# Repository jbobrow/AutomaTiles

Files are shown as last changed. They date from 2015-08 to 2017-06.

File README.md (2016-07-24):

# AutomaTiles

Read [here](GamePlatform.md) to learn about how to think of AutomaTiles as a game platform

AutomaTiles presents a new way to interact with cellular automata. In a physical form, each tile can be manipulated, and progresses based on an external metronome or user input. The same intimate knowledge a movie editor has with a film is shared with computation, as the user can control the speed at which the system evolves and handle individuals as they respond to input.

## Components
1. Virtual AutomaTiles
    1. [Automatiles.com/sim](http://automatiles.com/sim) (written by Jonathan Bobrow, rendered w/ Two.js)
    2. [Automatiles.com/sim/emoji](http://automatiles.com/sim/emoji) (modified version of Nicky Case's Emoji World Simulator)
2. Tangible AutomaTiles
    1. Hardware
        1. Electronics ([Components](https://docs.google.com/spreadsheets/d/1YpmN0rzX8dJSE3OYGx2io3yXud3R6zgf5WAVNdhyiFE))
        2. Printed Circuit Boards ([Rev. 3](http://automatiles.tumblr.com/post/133176987321/rev-3-boards-batch-of-100-automatiles-so-much-to))
        3. [Case Designs + Models](http://automatiles.tumblr.com/post/143452350711/automatiles-w-silicon-jackets-for-members-week)
    2. Firmware
        1. Registers, Pin mapping...
        2. Low Level code not accessible in API
    3. API
        1. [AutomaTile Library](Arduino)
        2. [Documentation](Examples/API.md)
        3. [Example Code](Examples)

##License
Copyright (c) 2015 MIT

Permission is hereby granted, free of charge, to any person obtaining a copy of this software and associated documentation files (the "Software"), to deal in the Software without restriction, including without limitation the rights to use, copy, modify, merge, publish, distribute, sublicense, and/or sell copies of the Software, and to permit persons to whom the Software is furnished to do so, subject to the following conditions:

The above copyright notice and this permission notice shall be included in all copies or substantial portions of the Software.

THE SOFTWARE IS PROVIDED "AS IS", WITHOUT WARRANTY OF ANY KIND, EXPRESS OR IMPLIED, INCLUDING BUT NOT LIMITED TO THE WARRANTIES OF MERCHANTABILITY, FITNESS FOR A PARTICULAR PURPOSE AND NONINFRINGEMENT. IN NO EVENT SHALL THE AUTHORS OR COPYRIGHT HOLDERS BE LIABLE FOR ANY CLAIM, DAMAGES OR OTHER LIABILITY, WHETHER IN AN ACTION OF CONTRACT, TORT OR OTHERWISE, ARISING FROM, OUT OF OR IN CONNECTION WITH THE SOFTWARE OR THE USE OR OTHER DEALINGS IN THE SOFTWARE.

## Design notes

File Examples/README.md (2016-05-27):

##AutomaTiles Examples##
The following examples are written using the AutomaTiles API for the Arduino IDE.

###Instructions for using the Arduino IDE w/ AutomaTiles###
1. copy the `AutomaTiles` folder into your Arduino directory i.e. `~/Documents/Arduino/hardware/`
2. launch or quit and relaunch Arduino IDE
3. in the top menu, go to `Tools > Board` and select `AutomaTile`
4. open an example and press the checkmark to make sure it compiles
5. Use an ISP of your choice and program your AutomaTiles!

###Examples###
**Color Gossip**
An example to show how colors can transition smoothly between each other. In this aesthetic example, tiles pulse white when alone, and then share colors when together. Pressing on one changes its color, and surrounding tiles try to match the color while transitioning smoothly over 3 seconds. With a large population, the result is a flow of colors, it is up to chance which one will contaminate them all.  

**Game of Life**
Based on John Conway's [Game of Life](https://en.wikipedia.org/wiki/Conway%27s_Game_of_Life), this example follows a simple set of rules to emerge some very complex behavior. Different AutomaTile arrangements create multiple static and dynamic equilibria

**Forest Fire**
A forest fire simulation based on Nicky Case's [Simulating the World in Emoji](ncase.me/simulating). Each tile represents a plot of land that can grow a tree, be struck by lightning, and catch on fire. Fires spread, Trees grow back, can you create the most resilient forest?

**Fracture**
A game that capitalizes on simple rules and thinking with your hands. Fracture is a competitive game for diversity. Each player has a color and they are trying to make all of their (6) tiles happy, represented by blinking. To make a tile happy, it needs to have at least 2 neighbors and only be touching colors different from itself. Players move by "fracturing" the board into 2 parts and reconfiguring it to make themselves more diverse and their opponents less diverse.

**PrototypeColors**
This is your best friend for prototyping any game. Tiles will shine brightly one a a predefined set of colors, in this case: red, orange, yellow, green, cyan, blue, magenta. If pressed the tile will switch to blink that color, or blink faster with another press. Holding down a tile for >1 sec goes to the next color and double pressing the tile <1 sec goes back to the previous color. With these easy deterministic rules that are not affected by neighbors, you can imagine how a game could work before having to program how it does work.

**Rock, Paper, Scissors**
A simple ruleset that results in a trippy chase of colors. Looks quite similar to a BZ-reaction.

**WireWorld**
A simple rulest based on [Wireworld](https://en.wikipedia.org/wiki/Wireworld), a cellular automata design of Brian Silverman in 1987. This ruleset simulates the flow of electrons through conductive wiring. Each electron is represented with a head and a tail for direction or flow of current, and spaces that aren't wires are fittingly considered insulation. The hexagonal ruleset requires a redefinition of logic gates (if all are possible)

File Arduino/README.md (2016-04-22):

# Arduino Board Type
Just add this folder to your <ARDUINO>\hardware\ directory.

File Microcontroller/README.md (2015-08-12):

# Microcontroller code
This is the code and libraries that will be running on the AutomaTiles. It handles all aspects of their operation.

## Programming Instructions
The ISP should be attached with Pin 1 towards the silk screened label and a coin cell should be in the device. The most recent stable build will be in AutomaTilesMain/AutomaTilesMain/Release, although the project can be easily rebuilt by opening it in Atmel Studio. As the clock speed of the ATTiny84 is only 1 MHz, any programming clock should be kept below 1/4 of that or 250kHz. To program from within Atmel Studio, open Tools>Device Programming and set your tool. Make sure to change the data clock to an appropriate value. Read the device signature to ensure you have communication. If that succeeds, go to the memories tab, ensure the proper .elf file is selected for the flash, and hit program.

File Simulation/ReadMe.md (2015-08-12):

# HTML Simulation

## Overview
A simulation of cellular automata in which the grid can be alternated between triangle, square, and hexagon. The neighborhoods update for each cell and the transition is animated, showing that each cell maintains its state. Rulesets should be user set and switchable through a GUI.

## File Structure
index.html
css/
js/

## Dependencies

1. Two.js
2. JQuery.js

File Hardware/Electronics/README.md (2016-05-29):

##AutomaTiles Electronics##
-	Eagle Parts (Library)
-	Schematics
-	Boards
-	Build of Materials (BOM)
-	Datasheets (maybe just links)

... anything else relevant to electronics

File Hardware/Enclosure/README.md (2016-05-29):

##AutomaTiles Enclosure##
-	Fusion360 models (maybe just links)
-	STLs
-	Build of Materials (BOM)

... anything else relevant to the enclosure

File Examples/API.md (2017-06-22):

## AutomaTiles API ##

Since the API is quite short, this is the current documentation for using it. It should be apparent on how to use it from some of the examples, but this can serve as a nice reference while you are writing your first programs for the AutomaTiles. 

**A default blank sketch**
```c
void setup() {  
   setButtonCallback(button); 
   setStepCallback(step);
}

void loop() {
	// continuous time logic here
}

void button() {
	// handle button down here
}

void step() {
	// discrete time logic here
}

```

### AutomaTile methods ###

**getNeighborStates**
```c
void getNeighborStates(uint8_t * result);
// pass it an array for the size of the neighborhood and it will return each neighbor’s state in that array. 
```
**sendStep**
```c
void sendStep(void);
// step forward in time, simulate ruleset
// maximum frequency 10Hz
// these do not cue up, i.e. if you send step more frequently, steps will be dropped 
```
**getTimer**
```c
uint32_t getTimer(void);
// returns a value of time in milliseconds (starts at 0 from battery in) 
```
**setColor**
```c
void setColor(const uint8_t color[3]);
// send this function (R,G,B) 0-255, color will change on next cycle 
```
**setState**
```c
void setState(uint8_t state);
// set the state of self 0-15 (limited due to communication of state and step frequency)
// invalid states are ignored, i.e. return without state change
// NOTE: empty spaces act as tiles of state 0 (treat this accordingly) 
```
**getState**
```c
uint8_t getState(void);
// get’s our own current state, 0-15 
```
**setStepCallback**
```c
void setStepCallback(cb_func cb); 
// pass your own function to setStepCallback, this function takes no arguments and returns nothing
// can be set once in the beginning of your application, but can also be hot-swapped during runtime
// defaults to do nothing (change this to default to flash red… or white) 
```
**setButtonCallback**
```c
void setButtonCallback(cb_func cb);
// pass your own function to setButtonCallback, this function takes no arguments and returns nothing
// can be set once in the beginning of your application, but can also be hot-swapped during runtime
// defaults to do nothing (change this to default to flash blue)
// NOTE: you cannot delay in the button callback (i.e. timer will not update while you are in the callback) 
```
**setLongButtonCallback**
```c
void setLongButtonCallback(cb_func cb, uint16_t ms);
// pass your own function to setLongButtonCallback, this function takes no arguments and returns nothing
// long button callback will be activated after a button has been pressed for n milliseconds (second parameter)
// can be set once in the beginning of your application, but can also be hot-swapped during runtime
// defaults to do nothing (change this to default to flash blue)
// NOTE: you cannot delay in the button callback (i.e. timer will not update while you are in the callback) 
```
**setLongButtonCallbackTime**
```c
void setLongButtonCallbackTime(uint16_t ms);
// set the amount of time it takes before the longButtonCallback is triggered
// can be hot-swapped during runtime
```
**setTimerCallback**
```c
void setTimerCallback(cb_func cb, uint16_t ms);
// set a custom timed callback, whatever you want, it will fire after a given amount of time
// can be hot-swapped during runtime
```
**setTimerCallbackTime**
```c
void setTimerCallbackTime(uint16_t ms);
// set the time for your callback seperately (maybe you want to update that time after setting it initially, perhaps it evolves over time
// can be hot-swapped during runtime
```
**setTimeout**
```c
void setTimeout(uint8_t seconds);
// sets the amount of time before sleeping in seconds
// defaults to 20 seconds
// if you want the automatile to never sleep send it 0, this will run down your battery 
```
**setMicOn**
```c
void setMicOn(void);
// turns the microphone on (i.e. listens for snaps) 
```
**setMicOff**
```c
void setMicOff(void);
// turns the microphone off (i.e. only steps forward from neighbor notification) 
```

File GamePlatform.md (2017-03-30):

# AutomaTiles as Game Platform

AutomaTiles allow a new type of game play as well as game design, and the following document will give a quick overview as to how to design for AutomaTiles and what their unique capabilities are.

## Overview

First of all, what are AutomaTiles? Each AutomaTile is a "smart" hexagonal tile, designed to be held in the hand or placed next to other tiles on a table. Magnets inside of each AutomaTile allow the hexagonal tile to maintain an organized gridlike structure without needing a board. Each tile has 3 properties:
1. it responds to presses (this is a tactile button press, the entire tile depresses ever so slightly, so players can feel when they have pressed on a tile, not simply touched)
2. it is social, which means it is aware of its neighbors, tiles on other sides, both presence as well as state (explained further below)
3. it is rythmic, can respond to sound (currently treated as a global message, for example a time step forward)

## Outputs

AutomaTiles communicate to the players through RGB illumination and their hue, saturation, brightness, as well as animated properties (i.e. pulsing, blinking, flashing...). Their is only a single uniform illumination for the entire tile, so think of each tile as being able to communicate relatively simple information.
In one example, a tile shows it is in a win condition by blinking rapidly, so all players are aware of the game state.

While illumination is how a single tile communicates to the players, the arrangement of the tiles also communicates something to the players. In one example, the arrangement of 10 tiles into different forms creates different behaviours of the whole. For example, if the tiles are representing trees in a forest fire, a tightly packed set of 10 will spread the fire quicker than a long single file line of tiles(trees). The player can reason this by seeing the arrangement of the board, and conversely, affect it by rearranging the board. Which brings me to inputs.

## Inputs

The simplest of inputs is a press. Each tile acts as a mechanical momentary button. The button can be used in a variety of ways, and can respond to a quick press, a long press, a double press...

The button press can be an input to change the state of a tile, or inform the tile of a users action. For example, in the forest fire ruleset, a single press strikes lightning upon a tile. If the tile is a tree, it will then change state to be on fire, and if it is not a tree, it will simply go on being not a tree, as well as not on fire.

The press can also be used to reveal information contained in a tile. For example, a tile representing a place in a game of minesweeper could reveal that it has a mine under it only when held with a long press. The button press in this case didn't add information to the system but is simply used to reveal information.

## Tile Communication

The tiles communicate with each of their six tile neighbors by receiving information every ~20 times per second. The information passed is in the form of a single integer (0-16). If no tile is present on a single side, the tile reads 0 on that side. (A tile can be present and send 0 as well, but it will be treated the same as space without a tile). What does this mean in simple terms? This means that each tile can tell each neighboring tile that it is in one of roughly 15 states. In the forest fire example, there are 3 states: tree, fire, soil. But what about lightning? that isn't a state, since it only affects the local tile, so it is animated through the illumination, but simply changes the tile's state from tree to fire.

AutomaTiles are setup to do this kind of communication often and reliably, but it is not the only way they can communicate. For longer forms of information, such as passing string-like information, there is a shared data buffer that could be utilized. This is experimental and not refined in the API, so I recommend first trying to rely on simple communication with the dozen or so states afforded above.

## Time

Game time for the tiles can be continuous, evaluating their state 20 times a second, or they can be discrete, evaluating their state only when a step is called. The step can be heard from the microphone or sensed via a pacemaker(special AutomaTile that silently flashes in the same way a metronome clicks).

In the forest fire example, time is discrete, which makes the spread of the fire controlled by the speed of the metronome. One could see this as a game mechanic, where each turn is a click or step forward.

In the game Fracture, a continuous game, the tiles are constantly evaluating their state so they can show players the most up to date representation of the current board state. This results in a board that is quickly responsive to arrangement, while discrete time makes a board that feels responsive to sound, pacemaker, or simply discrete time.

## Random vs. Deterministic

AutomaTiles can respond to their inputs and neighbors deterministically, where they will respond exactly the same way given the same inputs and neighbors everytime. This is the case in the example of Fracture or Game of Life. Players can learn how tiles will behave given a certain arrangement because of this deterministic ruleset.

Games often use randomness for a bit of chance involved in each move. A dice roll, or a weighted random value can be very useful in creating suspense or capturing the real world uncertainty.

Randomness can also be used with AutomaTiles with a bit of care and caution. Randomness is currently based on the internal clock of the ATtiny, which can provide a good enough source for a dice roll. In the example of the forest fire, each tile (plot of land) has an n% chance of growing a tree. That percent increases with the number of neighboring trees, to represent fertile ground, but it is random none-the-less. The caviat with randomness and AutomaTiles is that players must feel like the tiles are giving signal, not simply noise. If a player can't understand why a tile is behaving in the way it is, it will be confusing for everyone. That said, it is not a technical limitation, if you want a tile to be a random different color every time you press it, that is an easy program to write.

## Memory

While tiles can maintain a bit of a memory or history of what they have done, neighbors they've had, or how much time has passed, this is limited and it is important to remember that if this isn't transparent to the player, it will be very confusing. However, there will be elegant solutions in which a bit of stygmergy might just seep its way into a game and shed light on a beautiful invisible system that lies just beneath the surface.
(more on program space below)

## Trickiness

As you might have noticed, you have complete control over the way a tile displays itself to the player and the state a tile is actually in. It might be useful to have many states an only 2 visibly different appearances to the players. Conversely, it might be useful to have only two states and show many different illuminations.

The possibilities are many, feel free to look through the samples, they are only a few, but cover a couple of use cases.

Please feel free to ask about features, and if I didn't cover something that is in the API, I should, so point it out, it belongs here, too!

## Tech Details (for the game designer)

Each tile has it's own brain(attiny) with which it can run its own set of instructions. The examples I have given so far have the exact same code on every tile and the properties of the tiles together could be referred to as _emergent_. Game design with different code on some tiles vs others is also possible but might requires a skin or mark of some sort to differentiate the tiles (if the colors don't already suggest seperation).

### Memory

The ATtiny84 contains 8k of memory. The AutomaTiles firmware (or core library) takes up just under half of this space (~4k). That leaves an additional 4k for you to program your application.

The forest fire example uses ~5k memory (i.e. that application is only about 1k)

The game Fracture uses ~6k memory (... 2k application)

Additionally, there are 512 bytes of dynamic memory or RAM, which will be used for your global variables as well as your stack. If you use up all of that space with global variables, there will be no room for the stack and so weird sh...stuff will happen. Here is a nice breakdown of [memory management on AVR](http://thegaragelab.com/conserving-memory-on-an-avr/).

The space is limited, which suggests simple rules and straightforward code, which is beneficial to the players as well, since the aggregate always feels more complex than the single tile. When programming the tiles, optimizations for space can be made such as being specific about the types of variables. For example, using a `uint8_t` (1 byte... 8 bits) is a space efficient way to hold numbers 0-255, while using an `int` or an `uint16_t`(2 bytes... 16 bits) might be wasteful.

At first this task of memory management could seem daunting, but in practice, I have found the exercise of being concise and clever with code quite rewarding. Additionally, the Arduino IDE will let you know exactly how much space you are using everytime you press compile. If you open up a blank AutomaTile sketch and press compile, you will see that the sketch is ~4k (49%)
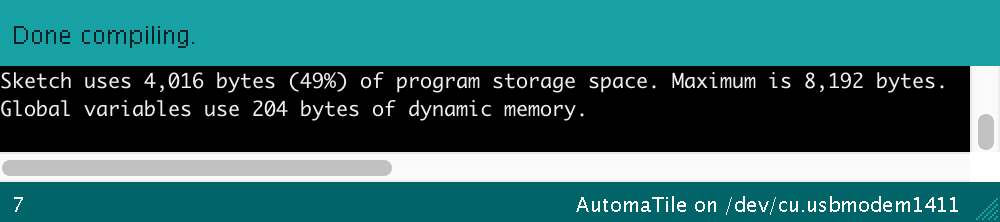
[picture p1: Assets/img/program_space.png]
Arduino IDE Screenshot


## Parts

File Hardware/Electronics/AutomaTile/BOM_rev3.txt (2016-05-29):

QUANTITY	PART NUMBER	Value	Device	Package	CUSTOMER REFERENCE	Description
1	1276-5110-1-ND	100k	R-US_R0603	R0603	R18	"RESISTOR, American symbol"
2	490-1532-1-ND	100nF	C-EUC0603	C0603	"C4, C6"	"CAPACITOR, European symbol"
4	490-6405-1-ND	10uF	C-EUC0603	C0603	"C2, C3, C7, C8"	"CAPACITOR, European symbol"
1	1276-5062-1-ND	1k	R-US_R0603	R0603	R17	"RESISTOR, American symbol"
2	490-1549-1-ND	1uF	C-EUC0603	C0603	"C1, C5"	"CAPACITOR, European symbol"
9	1276-5094-1-ND	22k	R-US_R0603	R0603	"R1, R2, R3, R4, R5, R6, R14, R15, R16"	"RESISTOR, American symbol"
6	1276-5069-1-ND	2k	R-US_R0603	R0603	"R7, R8, R9, R10, R11, R12"	"RESISTOR, American symbol"
1	490-4024-1-ND	4.7uH	L-US	R0603	L1	"INDUCTOR, American symbol"
1	1276-5054-1-ND	470	R-US_R0603	R0603	R13	"RESISTOR, American symbol"
1	568-9252-1-ND	74HCT2G17	74HCT2G17	SOT363	U5	IC BUFF DL SCHM TRG N-INV 6TSSOP
1	ATTINY84A-SSURCT-ND	ATTINY84-20SSU	ATTINY84-20SSU	SOIC127P600X175-14N	U1	8-bit Microcontroller with Bytes In-System Programmable Flash
1	BK-912-ND	BAT-HLD-2032-SMD	BAT-HLD-2032-SMD	BAT-HLD-2032-SMD	BT1	SMD battery holder for 2032 coincell
1	BSS138CT-ND	BSS138	MOSFET-NCHANNELSMD	SOT23-3	Q7	Generic NMOS footprint
1	BSS84CT-ND	BSS84	BSS84	SOT23-3	Q8	P-CHANNEL MOS FET
1	893-1181-1-ND	DC-DC-BOOST-XC9140	DC-DC-BOOST-XC9140	SOT-23-5	U2	5V output boost converter
6	1080-1358-1-ND	LED-SIDELOOKING-IR26-51C	LED-SIDELOOKING-IR26-51C	LED-SIDELOOKING	"D1, D2, D3, D4, D5, D6"	Sidelooking IR LED
1	MCP6001T-I/OTCT-ND 	MCP601OT	MCP601OT	SOT23-5	U4	Single Op Amp 2.7V to 6.0V Single Supply CMOS
1	423-1394-1-ND 	MICROPHONE-MEMS	MICROPHONE-MEMS	MEMS-MIC	MK1	Mems microphone
6	754-1365-1-ND 	PHOTOTRANSISTOR-SFH-325LOW-PROFILE	PHOTOTRANSISTOR-SFH-325LOW-PROFILE	SMD-PHOTOTRANSISTOR-LP	"Q1, Q2, Q3, Q4, Q5, Q6"	Sidelooking NPN phototransistor
1	P12970SCT-ND	TACT-SWITCH-GENERAL	TACT-SWITCH-GENERAL	TACT-SWITCH-6MM	S1	General Off-Mom 6mm tactile switch

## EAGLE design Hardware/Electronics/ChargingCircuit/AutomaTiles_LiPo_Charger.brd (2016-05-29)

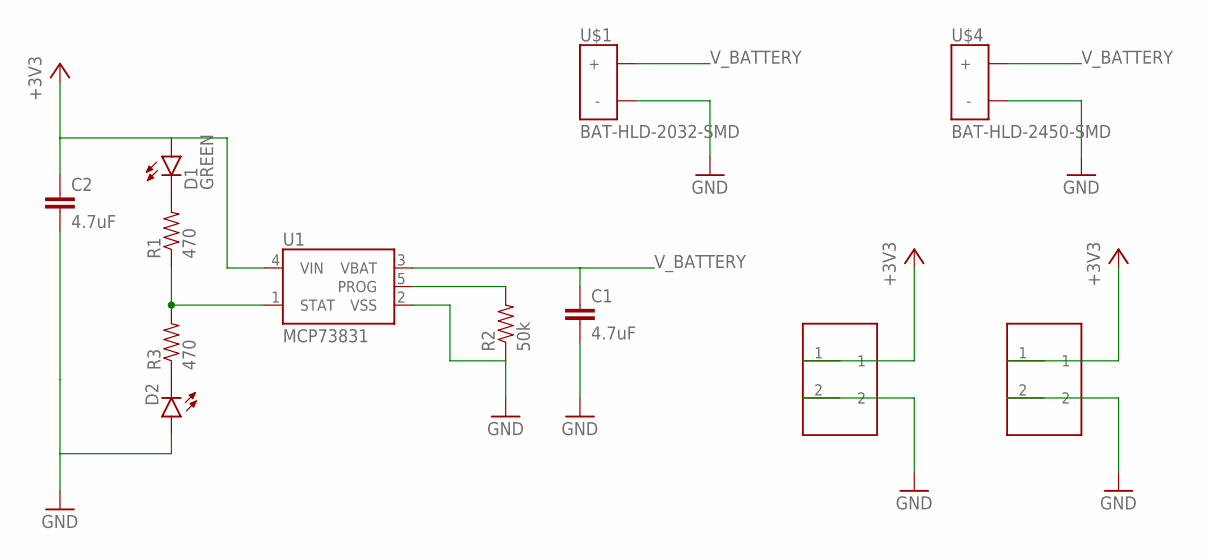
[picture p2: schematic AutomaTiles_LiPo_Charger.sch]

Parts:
C1, C2: 4.7uF; 0603-CAP
D1: GREEN; LED-0603
D2: LED-YELLOW0603; LED-0603
R1, R3: 470; 0603-RES
R2: 50k; 0603-RES
U1: MCP73831; SOT23-5
U$1: BAT-HLD-2032-SMD
U$2, U$3: 1X2_FEMALE_HEADER
U$4: BAT-HLD-2450-SMD

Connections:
+3V3: C2.1, D1.A, U1.4 (VIN), U$2.1, U$3.1
GND: C1.2, C2.2, D2.A, R2.1, U1.2 (VSS), U$1.GND (-), U$2.2, U$3.2, U$4.GND (-)
unnamed: R1.1, R3.2, U1.1 (STAT)
unnamed: R2.2, U1.5 (PROG)
unnamed: D1.C, R1.2
unnamed: D2.C, R3.1
V_BATTERY: C1.1, U1.3 (VBAT), U$1.POS1 (+), U$1.POS2 (+), U$4.POS1 (+), U$4.POS2 (+)

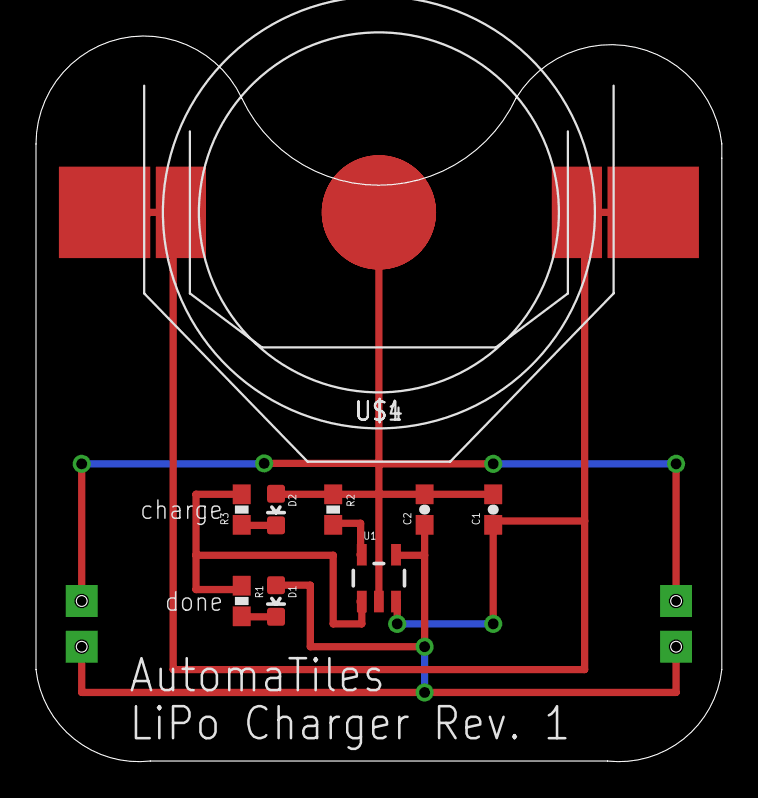
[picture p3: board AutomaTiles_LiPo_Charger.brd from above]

Board: 2 copper layers, 38.1 x 40.3 mm, 12 parts (0 on the bottom side), 7 nets.

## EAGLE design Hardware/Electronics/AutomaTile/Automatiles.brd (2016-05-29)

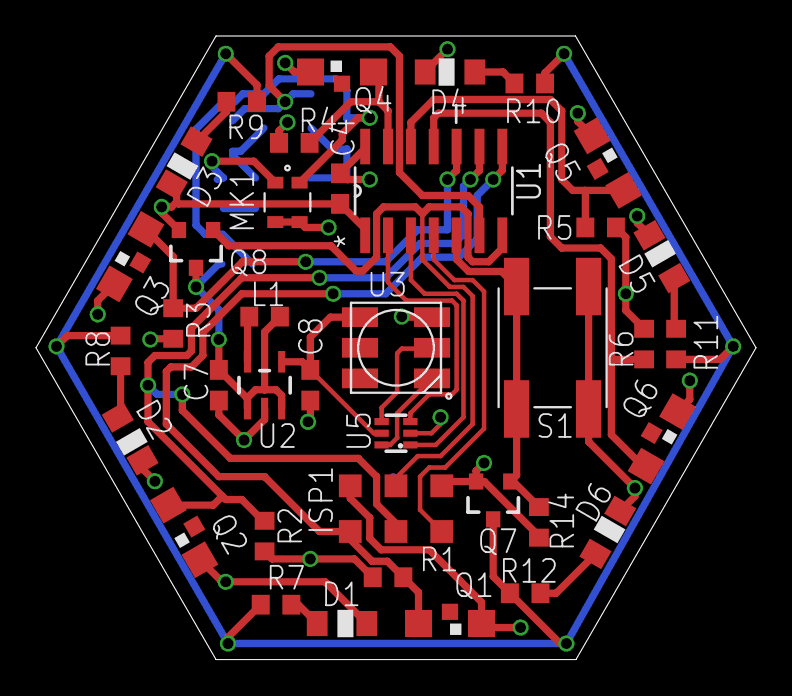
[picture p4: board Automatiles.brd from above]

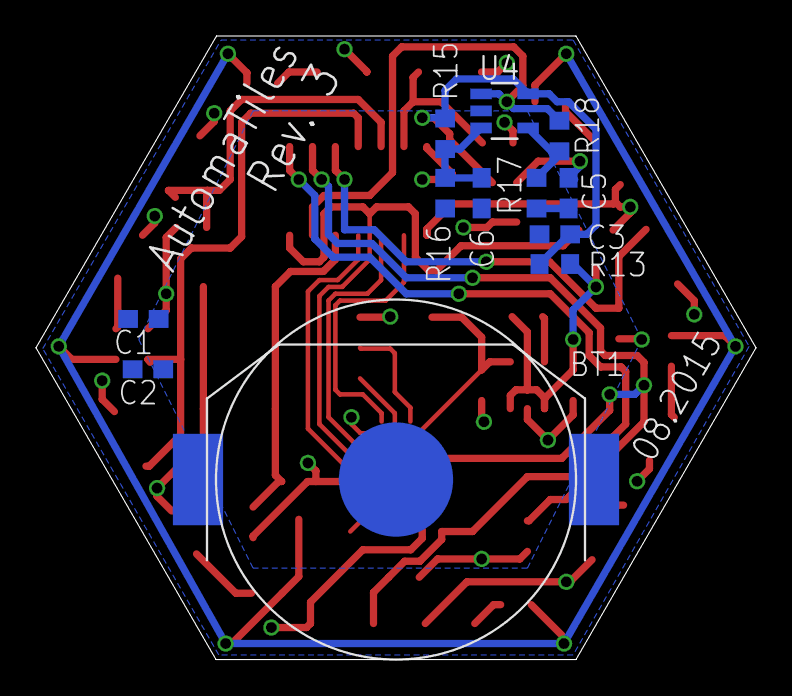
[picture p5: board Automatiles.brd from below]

Board: 2 copper layers, 40.0 x 34.6 mm, 50 parts (12 on the bottom side), 31 nets.

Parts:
BT1: BAT-HLD-2032-SMD
C1, C5: 1uF; C0603
C2, C3, C7, C8: 10uF; C0603
C4, C6: 100nF; C0603
D1, D2, D3, D4, D5, D6: LED-SIDELOOKING-IR26-51C; LED-SIDELOOKING
ISP1: AVRISP-POGO
L1: 4.7uH; R0603
MK1: MICROPHONE-MEMS; MEMS-MIC
Q1, Q2, Q3, Q4, Q5, Q6: PHOTOTRANSISTOR-SFH-325LOW-PROFILE; SMD-PHOTOTRANSISTOR-LP
Q7: BSS138; SOT23-3
Q8: BSS84; SOT23-3
R1, R2, R3, R4, R5, R6, R14, R15, R16: 22k; R0603
R7, R8, R9, R10, R11, R12: 2k; R0603
R13: 470; R0603
R17: 1k; R0603
R18: 100k; R0603
S1: TACT-SWITCH-GENERAL; TACT-SWITCH-6MM
U1: ATTINY84-20SSU; SOIC127P600X175-14N
U2: DC-DC-BOOST-XC9140; SOT-23-5
U3: APA102C; WS2812
U4: MCP601OT; SOT23-5
U5: 74HCT2G17; SOT363

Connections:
5V: C8.2, U2.VOUT, U3.NC, U5.5
GND: BT1.GND, C1.1, C2.1, C3.1, C4.2, C6.2, C7.1, C8.1, ISP1.GND, MK1.GNDA, MK1.GNDB, Q7.2, R1.1, R2.1, R3.1, R4.1, R5.1, R6.1, R14.2, R16.2, U1.14, U2.GND, U3.VDD, U4.2, U5.2
LX: L1.2, U2.LX
unnamed: U1.2, U5.3
unnamed: U1.3, U5.1
unnamed: D1.C, R7.2
unnamed: D2.C, R8.2
unnamed: D3.C, R9.2
unnamed: D4.C, R10.2
unnamed: D5.C, R11.2
unnamed: D6.C, R12.2
unnamed: Q7.3, R7.1, R8.1, R9.1, R10.1, R11.1, R12.1
unnamed: Q7.1, R14.1, S1.A, S1.A', U1.5
unnamed: C5.2, MK1.OUTPUT
unnamed: C6.1, R15.2, R16.1, U4.3
unnamed: R17.1, R18.2, U4.4
unnamed: U3.DI, U5.4
unnamed: R18.1, U1.6, U4.1
unnamed: U3.DO, U5.6
unnamed: ISP1.RESET, U1.4
unnamed: ISP1.MOSI, Q8.1, U1.7
PHOTO0: ISP1.MISO, Q1.EMITTER, R1.2, U1.8
PHOTO1: ISP1.SCK, Q2.EMITTER, R2.2, U1.9
PHOTO2: Q3.EMITTER, R3.2, U1.10
PHOTO3: Q4.EMITTER, R4.2, U1.13
PHOTO4: Q5.EMITTER, R5.2, U1.12
PHOTO5: Q6.EMITTER, R6.2, U1.11
TEST: C5.1, R17.2
V+: C3.2, MK1.VCC, R13.2, R15.1, U4.5
VCC: BT1.POS1, BT1.POS2, C1.2, C2.2, C4.1, D1.A, D2.A, D3.A, D4.A, D5.A, D6.A, ISP1.VCC, Q1.COLLECTOR, Q2.COLLECTOR, Q3.COLLECTOR, Q4.COLLECTOR, Q5.COLLECTOR, Q6.COLLECTOR, Q8.2, S1.B, S1.B', U1.1
VCCINT: C7.2, L1.1, Q8.3, R13.1, U2.CE, U2.VBAT

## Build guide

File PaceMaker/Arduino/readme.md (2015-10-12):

Instructions for ESP8266 as Arduino

based on: http://blog.nyl.io/tag/esp8266/

How to setup?

How to program?

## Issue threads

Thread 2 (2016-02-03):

Fix RELEASE Build Mode in Atmel Studio

jbobrow, 2016-02-03:
Currently only builds in debug mode.

Closed 2016-10-22.

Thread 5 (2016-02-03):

Sleeper hold + yawning (i.e. sleep transmission)

jbobrow, 2016-02-03:
Allow a tile to send other tiles to sleep similar to program mode. (Note: IR LEDs are full bright when button is pressed)

Implementation would look like the following
```
// press for n seconds,
// send signal saying force sleep for 2 seconds
// wait for 3 seconds (allows surrounding tiles to broadcast without waking you)
// then go to sleep
```

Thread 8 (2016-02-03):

Arduino compatible library

jbobrow, 2016-02-03:
Look into whether it is possible to use the Arduino IDE to program AutomaTiles (should be doable... doesn't require the bootloader...) Similar in theory to http://highlowtech.org/?p=1695

Closed 2016-10-22.

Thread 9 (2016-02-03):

API - allow user to specify number of states able to be transmitted

jbobrow, 2016-02-03:
Note: this has a direct effect on update speed for the AutomaTiles... but might not be a big deal (i.e. every added bit for transmission doubles the possible states transmitted and only requires an additional milliseconds to transmit/receive)

Currently AutomaTiles transmit up to 15 states and have a refresh rate of ~60Hz... the trade off for more states is a slower refresh rate, perhaps refresh rate can also be specified in the API.

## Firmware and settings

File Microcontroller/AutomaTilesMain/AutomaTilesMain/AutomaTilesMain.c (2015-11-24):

/*
 * AutomaTilesMain.c
 *
 * Created: 7/14/2015 15:53:13
 *  Author: Joshua
 */ 


#include <inttypes.h>
#include <avr/io.h>
#include <avr/interrupt.h>
#include <avr/cpufunc.h>
#include <avr/sleep.h>

#include "Pins.h"
#include "Inits.h"
#include "APA102C.h"

volatile static int16_t holdoff = 2000;//for temporarily preventing click outputs
volatile static uint8_t click = 0;//becomes non-zero when a click is detected
volatile static uint8_t sync = 0;//becomes non-zero when synchronization pulses need to be sent out
volatile static uint8_t state = 0;//current state of tile
volatile static uint32_t timer = 0;//.1 ms timer tick
volatile static uint32_t times[6][4];//ring buffer for holding leading  detection edge times for the phototransistors
volatile static uint8_t timeBuf[6];//ring buffer indices

const uint32_t TIMEOUT = 20;
volatile static uint32_t sleepTimer = 0;
volatile static uint32_t powerDownTimer = 0;
volatile static uint8_t wake = 0;

const uint8_t PULSE_WIDTH = 8;//1/2 bit of manchester encoding, time in ms
volatile static uint8_t progDir = 0;//direction to pay attention to during programming. Set to whichever side put the module into program mode.
volatile static uint8_t comBuf[64];//buffer for holding communicated messages when programming rules (oversized)
volatile static uint16_t bitsRcvd = 0;//tracking number of bits received for retransmission/avoiding overflow
static uint8_t seqNum = 0;//Sequence number used to prevent circular retransmission of data

// init to the default rulestate for automatiles
volatile static uint8_t birthRules[7] = {0,0,1,1,0,0,0}; // if true, should be born
volatile static uint8_t deathRules[7] = {1,1,0,0,1,1,1}; // if true, should die (gotta find a better metaphor, this is too sad)
volatile static uint8_t numStates = 2; // sets the age of an automatile
volatile static uint8_t soundEn = 1; //if true, react to sound

uint8_t colors[][3] = //index corresponds to state
{
	{0x55,0x00,0x00},
	{0x00,0x55,0xAA},
	{0x7F,0x7F,0x00},
	{0xAA,0x55,0x00},
	{0xFF,0x00,0x00},
	{0xAA,0x00,0x55},
	{0x7F,0x00,0x7F},
	{0x55,0x00,0xAA},
	{0x00,0x00,0xFF},
	{0x00,0x55,0xAA},
	{0x00,0x7F,0x7F},
	{0x00,0xAA,0x55},		
	{0x00,0xFF,0x00},
	{0x55,0xAA,0x00}
};

const uint8_t CYCLE_TIME = 32;
uint8_t cycleTimer = 0;
uint32_t lastTime = 0;
const uint8_t breatheCycle[] = 
{64, 72, 81, 90, 100, 110, 121, 132,
144, 156, 169, 182, 196, 211, 225, 241,
255, 241, 225, 211, 196, 182, 169, 156,
144, 132, 121, 110, 100, 90, 81, 72};
/*{64, 68, 72, 76, 81, 85, 90, 95, 100, 105, 110, 116, 121, 127, 132,	138, 
144, 150, 156, 163, 169, 176, 182, 189, 196, 203, 211, 218, 225, 233, 241, 249,
255, 249, 241, 233, 225, 218, 211, 203, 196, 189, 182, 176, 169, 163, 156, 150,
144, 138, 132, 127, 121, 116, 110, 105, 100, 95, 90, 85, 81, 76, 72, 68};*/

const uint8_t dark[3] = {0x00, 0x00, 0x00};
const uint8_t recieveColor[3] = {0x00, 0x7F, 0x00};
const uint8_t transmitColor[3] = {0xAA, 0x55, 0x00};
	
uint8_t bright(uint8_t val){
	if(val >= 127){
		return 255;
	}
	if(val == 0){
		return 4;
	}
	return val<<1;
}

enum MODE
{
	sleep,
	running,
	recieving,
	transmitting
} mode;
	
static void getStates(uint8_t * result);
static void parseBuffer();

int main(void)
{
	//Initialization routines
	initIO();
	setPort(&PORTB);
	sendColor(LEDCLK,LEDDAT,colors[0]);
	sei();
	initAD();
	initTimer();
	set_sleep_mode(SLEEP_MODE_PWR_DOWN);
	sleep_enable();
	//Set up timing ring buffers
	for(uint8_t i = 0; i<6; i++){
		timeBuf[i]=0;
	}
	
	mode = running;
	
    while(1)

    {	
		if(mode==sleep){
			disAD();
			//
			DDRB &= ~IR;//Set direction in
			PORTB &= ~IR;//Set pin tristated
			sendColor(LEDCLK, LEDDAT, dark);
			PORTA |= POWER;//Set LED and Mic power pin high (off)
			wake = 0;
			while(!wake){
				cli();
				uint32_t diff = timer-powerDownTimer;
				sei();
				if(diff>500){
					sleep_cpu();
					wake = 1;
				}
			}
			holdoff=500;
			PORTA &= ~POWER;
			
			uint8_t done = 0;
			cli();
			uint32_t startTime = timer;
			sei();
			while(!done){
				cli();
				uint32_t time = timer;
				sei();
				if(time-startTime>250){
					done=1;
				}
			}
			
			done = 0;
			cli();
			startTime = timer;
			sei();
			DDRB |= IR;//Set direction out
			PORTB |= IR;//Set pin on
			sendColor(LEDCLK, LEDDAT, transmitColor);
			while(!done){
				cli();
				uint32_t time = timer;
				sei();
				if(time-startTime>500){
					done=1;					
				}				
			}
			enAD();
			powerDownTimer = timer;
			sleepTimer = timer;
			mode = running;
		}else if(mode==running){
			if(click){
				uint8_t neighborStates[6];
				getStates(neighborStates);
				uint8_t clickColor[] = {bright(colors[state][0]),bright(colors[state][1]),bright(colors[state][2])}; 
				sendColor(LEDCLK, LEDDAT, clickColor);
				uint8_t numOn = 0;

				sync = 3;//request sync pulse be sent at next possible opportunity (set to 4 for logistical reasons)

				for (uint8_t i = 0; i< 6; i++)
				{
					//at the moments specific state detection is a bit iffy, 
					//so mapping any received state>1 to a state of 1 works for now
					if(neighborStates[i]>0){
						numOn++;
					}	
				}
				//Logic for what to do to the state based on number of on neighbors
				if(state == 0) {
					if(birthRules[numOn]) {
						state=1;
					}
				}
				else {
					if(deathRules[numOn]) {
						state = (state + 1) % numStates;
					}
				}
				//End logic

				//prevent another click from being detected for a bit
				holdoff = 100;
				click = 0;
			}
		
			//periodically update LED once every 0x3F = 64 ms (fast enough to feel responsive)
			cli();
			if(!(timer & 0x3F)){
				if(timer!=lastTime){
					lastTime=timer;
					cycleTimer++;
					cycleTimer %= CYCLE_TIME;
					uint8_t outColor[3] = {(colors[state][0]*breatheCycle[cycleTimer])/255, 
										   (colors[state][1]*breatheCycle[cycleTimer])/255,
										   (colors[state][2]*breatheCycle[cycleTimer])/255};
					sendColor(LEDCLK, LEDDAT, outColor);
				}
			}
			sei();
			//check if we enter sleep mode
			cli();//temporarilly prevent interrupts to protect timer
			if(timer-sleepTimer>1000*TIMEOUT){
				mode = sleep;
			}
			sei();
		}else if(mode==recieving){
			//disable A/D
			disAD();
			//set photo transistor interrupt to only trigger on specific direction
			setDir(progDir);
			//set recieving color
			sendColor(LEDCLK, LEDDAT, recieveColor);	
			//record time entering the mode for timeout
			cli();
			uint32_t modeStart = timer;
			sei();
			while(mode==recieving){//stay in this mode until instructed to leave or timeout
				cli();
				uint32_t diff = timer-modeStart;
				sei();
				if(diff>3000){//been in mode 1 for more than 5 seconds
					mode = transmitting;					
				}
			}
		}else if(mode==transmitting){
			//disable Phototransistor Interrupt
			setDirNone();
			//set LED to output
			DDRB |= IR;//Set direction out
			//send 5 pulses
			uint32_t startTime = timer;
			if(bitsRcvd>=8 && comBuf[0]!=seqNum){
				for(int i=0; i<5; i++){
					while(timer==startTime){
						PORTB &= ~IR;
					}
					startTime = timer;
					while(timer==startTime){
						PORTB |= IR;
					}
					startTime = timer;
				}
				parseBuffer();
			}else{
				bitsRcvd = 0;
			}
			
			startTime = timer;
			sendColor(LEDCLK, LEDDAT, transmitColor);//update color while waiting			
			while(timer<startTime+20);//pause for mode change
			startTime = timer;
			uint16_t timeDiff;
			uint16_t bitNum;
			while(bitsRcvd>0){
				timeDiff = (timer-startTime)/PULSE_WIDTH;
				bitNum = timeDiff/2;
				if(timeDiff%2==0){//first half
					if(comBuf[bitNum/8]&(1<<bitNum%8)){//bit high
						PORTB &=  ~IR;
					}else{//bit low
						PORTB |=  IR;
					}
				}else{//second half
					if(comBuf[bitNum/8]&(1<<bitNum%8)){//bit high
						PORTB |=  IR;
						}else{//bit low
						PORTB &=  ~IR;
					}
				}
				if(bitNum>=bitsRcvd){
					bitsRcvd = 0;
				}				
			}
			//while(timer<startTime+2000);//pause for effect
			
			//done transmitting
			//re-enable A/D
			enAD();
			//re-enable all phototransistors
			setDirAll();
			state = 0;
			mode = running;

		}
	}
}

/* Receives two bytes containing birth rules and death rules
 * Each byte contains 0 or 1 in each position to 
 * represent true or false if born or killed off with n neighbors
 */
static void setRules(uint8_t br, uint8_t dr) {
	birthRules[0] = br&(1<<0);
	birthRules[1] = br&(1<<1);
	birthRules[2] = br&(1<<2);
	birthRules[3] = br&(1<<3);
	birthRules[4] = br&(1<<4);
	birthRules[5] = br&(1<<5);
	birthRules[6] = br&(1<<6);
	
	deathRules[0] = dr&(1<<0);
	deathRules[1] = dr&(1<<1);
	deathRules[2] = dr&(1<<2);
	deathRules[3] = dr&(1<<3);
	deathRules[4] = dr&(1<<4);
	deathRules[5] = dr&(1<<5);
	deathRules[6] = dr&(1<<6);
}

/* Set the number of states each automatile will go through
 * this is effectively an age... i.e. after this many die states, 
 * it will actually die 
 */
static void setNumStates(uint8_t num) {
	numStates = num;
}

static void setColors(volatile uint8_t* buf){
	colors[0][0] = buf[0];
	colors[0][1] = buf[1];
	colors[0][2] = buf[2];
	colors[1][0] = buf[3];
	colors[1][1] = buf[4];
	colors[1][2] = buf[5];
}

/* Uses the current state of the times ring buffer to determine the states of neighboring tiles
 * For each side, to have a non-zero state, a pulse must have been received in the last 100 ms and two of the
 * last three timing spaces must be equal.
 * 
 * State is communicated as a period for the pulses. Differences are calculated between pulses and if a consistent
 * difference is found, that translates directly to a state
 * Accuracy is traded for number of states (i.e. 5 states can be communicated reliably, while 10 with less robustness)
*/
static void getStates(uint8_t * result){
	cli();//Disable interrupts to safely grab consistent timer value
	uint32_t curTime = timer;
	uint32_t diffs[3];
	for(uint8_t i = 0; i < 6; i++){
		if((curTime-times[i][timeBuf[i]])>100){//More than .1 sec since last pulse, too long
			result[i] = 0;
		}else{//received pulses recently
			uint8_t buf = timeBuf[i];//All bit-masking is to ensure the numbers are between 0 and 3
			diffs[0] = times[i][buf] - times[i][(buf-1)&0x03];
			diffs[1] = times[i][(buf-1)&0x03] - times[i][(buf-2)&0x03];
			diffs[2] = times[i][(buf-2)&0x03] - times[i][(buf-3)&0x03];
			if(diffs[0]>100 || diffs[1]>100 || diffs[2] > 100){//Not enough pulses recently
				result[i] = 0;
			}else{//received enough pulses recently
				//rounding 
				diffs[0] >>= 3;
				diffs[1] >>= 3;
				diffs[2] >>= 3;
				//checking if any two of the differences are equal and using a value from the equal pair
				if(diffs[0] == diffs[1] || diffs[0] == diffs[2]){
					result[i] = (uint8_t) diffs[0];
				}else if(diffs[1] == diffs[2]){
					result[i] = (uint8_t) diffs[1];
				}else{//too much variation
					result[i] = 0;
				}
			}
		}
	}	
	sei();//Re-enable interrupts
}

//parse received data buffer and update values
//1 -> next 2 bytes are rules
//2 -> next byte is number of states
//3 -> next 6 bytes are colors
//4 -> disable mic
//5 -> enable mic
static void parseBuffer(){
	seqNum = comBuf[0];
	int i = 1;
	uint8_t numBytes = bitsRcvd/8;
	while(i<numBytes){
		if(comBuf[i]==1){
			if(i+2<numBytes){
				setRules(comBuf[i+1],comBuf[i+2]); 
			}
			i+=3;
		}else if(comBuf[i]==2){
			if(i+1<numBytes){
				setNumStates(comBuf[i+1]);
			}
			i+=2;
		}else if(comBuf[i]==3){
			if(i+6<numBytes){
				setColors(comBuf+i+1);
			}
			i+=7;
		}else if(comBuf[i]==4){
			soundEn = 0;
			i++;
		}else if(comBuf[i]==5){
			soundEn = 1;
			i++;
		}else{
			i++;
		}
	}
}

//Timer interrupt occurs every 1 ms
//Increments timer and controls IR LEDs to keep their timing consistent
ISR(TIM0_COMPA_vect){
	static uint8_t IRcount = 0;//Tracks cycles for accurate IR LED timing
	static uint8_t sendState = 0;//State currently being sent. only updates on pulse to ensure accurate states are sent
	timer++;
	if(mode==running){
		IRcount++;
		if(IRcount>=(uint8_t)(sendState*8+4)){//State timings are off by 4 from a multiple of 8 to help with detection
			IRcount = 0;
			if(sync==0){
				sendState = state;
			}
		}
		
		if(IRcount==5){ 
			PORTB |= IR;
			DDRB |= IR;
		}else if(IRcount==7&&sync>1){
			PORTB |= IR;
			DDRB |= IR;		
			sync = 1;
		}else if(IRcount==9&&sync==1){
			PORTB |= IR;
			DDRB |= IR;
			sync = 0;
		}else if(sendState==0&&sync>0){//0 case is special
			if((IRcount&0x01)!=0){
				PORTB |= IR;
				DDRB |= IR;			
				sync -= 1;
				}else{
				DDRB &= ~IR;//Set direction in
				PORTB &= ~IR;
			}
		}else{
			DDRB &= ~IR;//Set direction in
			PORTB &= ~IR;//Set pin tristated
		
			if(IRcount<5){
				if(PINB & BUTTON){//Button active high
					if(holdoff==0){
						state = !state;//simple setup for 2 state tile
						sleepTimer = timer;
						powerDownTimer = timer;
					}
					holdoff = 500;//debounce and hold state until released
				}
			}
		}
	}else if(mode == recieving){//recieving data, ensure led off
		DDRB &= ~IR;//Set direction in
		PORTB &= ~IR;//Set pin tristated		
	}
}


//INT0 interrupt triggered when the pushbutton is pressed
ISR(PCINT1_vect){
	wake = 1;
}

//Pin Change 0 interrupt triggered when any of the phototransistors change level
//Checks what pins are newly on and updates their buffers with the current time
ISR(PCINT0_vect){
	static uint8_t prevVals = 0; //stores the previous state so that only what pins are newly on are checked
	static uint8_t pulseCount[6]; //stores counted pulses for various actions
	static uint32_t oldTime = 0; //stored the previous time for data transmission
	uint8_t vals = PINA & 0x3f; //mask out phototransistors
	uint8_t newOn = vals & ~prevVals; //mask out previously on pins
	
	powerDownTimer = timer;
	
	if(mode==running){
		for(uint8_t i = 0; i < 6; i++){
			if(newOn & 1<<i){ //if an element is newly on, 
				if(timer-times[i][timeBuf[i]]<10){//This is a rapid pulse. treat like a click
					pulseCount[i]++;
					if(pulseCount[i]==2){
						if(holdoff==0){
							click = 1;
							wake = 1;
							sleepTimer = timer;
						}
					}
					if(pulseCount[i]>=4){//There have been 4 quick pulses. Enter programming mode.							
						mode = recieving;
						progDir = i;
					}					
				}else{//Normally timed pulse, process normally
					pulseCount[i]=0;
					timeBuf[i]++;
					timeBuf[i] &= 0x03;
					times[i][timeBuf[i]] = timer;
				}
			}
		}
	}else if(mode==recieving){
		if(((prevVals^vals)&(1<<progDir))){//programming pin has changed
			if(timer-oldTime > (3*PULSE_WIDTH)/2){//an edge we care about
				if(timer-oldTime > 4*PULSE_WIDTH){//first bit. use for sync
					bitsRcvd = 0;
					for(int i = 0; i < 64; i++){//zero out buffer
						comBuf[i]=0;
					}					
				}
				oldTime = timer;				
				if(bitsRcvd<64*8){
					uint8_t bit = ((vals&(1<<progDir))>>progDir);
					comBuf[bitsRcvd/8] |= bit<<(bitsRcvd%8);
					bitsRcvd++;
				}				
			}
		}
	}
	prevVals = vals;
}

//ADC conversion complete interrupt
//Calculates a running median for zeroing out signal
//Then calculates a running median of deltas from the median to check for exceptional events
//If a delta is very high compared to the median, a click is detected and click is set to non-0
ISR(ADC_vect){
	//Values saved for derivative calculation
	static uint16_t median = 1<<15;
	static uint16_t medDelta = 1<<5;
	
	uint8_t adc;	
	
	adc = ADCH;// Record ADC value
	sei(); //re-enable interrupts, allow this calculation to be interrupted
	
	//update running median. Error on high side.
	//note that due to comparison, the median is scaled up by 2^8
	if((adc<<8)<median){
		median--;
		}else{
		median++;
	}
	uint16_t delta;
	if(median > (adc<<8)){// Calculate delta
		delta = (median>>8)-adc;
		}else{
		delta = adc-(median>>8);
	}
	
	//Update running delta median. Error on high side.
	//note that due to comparison, the median is scaled up by 2^4=16
	if((delta<<4)<medDelta && medDelta > 10){ 
		medDelta--;
		}else{
		medDelta++;
	}
	
	if(holdoff<0){//edge case protection
		holdoff = 0;
	}
	
	if(holdoff == 0){//holdoff can be set elsewhere to disable click being set for a period of time
		if(medDelta < delta){//check for click. as the median delta is scaled up by 16, an exceptional event is needed.
			if(soundEn){
				click = delta;//Board triggered click as soon as it could (double steps)
				cli();
				sleepTimer = timer;
				sei();
			}
		}
	}else{
		holdoff--;
	}
}

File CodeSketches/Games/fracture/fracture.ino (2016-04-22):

/*  Fracture (Game)
 *  
 *  Setup: For 3-6 players. Each player gets 5-6 tiles of a specific color.
 *         Game starts will all tiles connected, but completely segregated by color.
 *
 *  Goal: Get your tiles to be touching only other players tiles.
 *        Note: your tiles must be touching two other tiles to feel happily diverse.
 *
 *  Turns: Start from a player of choice and then go clockwise taking turns.
 *         A turn consists of fracturing the population into two sub populations,
 *         and then connecting them back together in any way you please.
 *  
 *  When a player has a tile fully diversified, it will blink,
 *  first player to have all of their tiles blink wins. 
 *
 *  Game devopment by: Celia Pearce, Jeanie Choi, Isabella Carlson, Mike Lazer-Walker, Joshua Sloane
 *
 *  by Jonathan Bobrow
 *  01.28.2016
 */

uint32_t lastUpdateTime = 0;
uint32_t updateFrequency = 50;  //milliseconds

uint8_t diversityValue;
uint8_t possibleDiversityValue;

uint8_t neighbors[6];

uint8_t colors[6][3] = {{255,0,0},          // Red
                         {0,255,0},         // Green
                         {0,0,255},         // Blue
                         {255,0,255},       // Magenta
                         {255,255,0},       // Yellow
                         {0,255,255}};      // Cyan

// blink off color
uint8_t darkColor[3] = {0,0,0};

// the color we will actually show
uint8_t outputColor[3];

// minimum number of neighbors present
// to be happy at all (i.e. tiles with only 
// one neighbor, feel left out)
uint8_t minNeighbors = 2; 

// this gets triggered when we press the button
void button() {
  // update the color/type we are
  // increment our state value by one between the range of (1-6)
  setState(getState()%6 + 1);
}

void step() {
  // Do nothing here
}

void setup() {
  setLongButtonCallback(button, 2000);  // setup a button handler (only for long press)
  setStepCallback(step);          // setup a step handler
  setState(1);                    // set initial state
  setMicOff();                    // listen to step forward
  setTimeout(600);                // 10 minutes
}

void loop() {
   
  if(getTimer() - lastUpdateTime > updateFrequency) {

    getNeighborStates(neighbors);

    // get diversity
    diversityValue = 0;
    possibleDiversityValue = 0;
    for(uint8_t i=0; i<6; i++) {
      // check if we have a neighbor
      if(neighbors[i] != 0) {
        possibleDiversityValue++;
        // now we have a neighbor check its state
        if(neighbors[i] != getState()) {
          diversityValue++;
        }
      }
    }

    // happiness integer (0-6)
    uint8_t happiness = possibleDiversityValue == 0 ? 6 : (diversityValue * 6) / (possibleDiversityValue); 
    if(possibleDiversityValue < minNeighbors)
      happiness = 0;

    // sadness is the inverse of happiness
    uint8_t sadness = 6 - happiness;

    // now make the light bright based on how happy we are
    // (or dim it based on how sad we are...)
    outputColor[0] = colors[getState()-1][0] >> sadness;  // Red output value
    outputColor[1] = colors[getState()-1][1] >> sadness;  // Green output value
    outputColor[2] = colors[getState()-1][2] >> sadness;  // Blue output value
    /*  NOTE: BITSHIFT OPERATOR
     *  >>n operator simply divides the value by 2^n
     *  (i.e. 128 >> 2 = 32 (128/2^2) -> (128/4) -> 32)
     *  super handy for quick division or multiplication by powers of 2
     */
    
    // to help players know when the brightest value is showing
    // blink if in happiest state or simply display the output color
    if(happiness == 6 &&(getTimer() % 500) > 250 ) {
        setColor(darkColor);
    }else {
        setColor(outputColor);  
    }

    // update our update time
    lastUpdateTime = getTimer();
  }
}

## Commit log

2015-06-21 adding frequency to contol panel and cleaning up buttons. Also added on and off color to each cell
2015-06-21 printing out neighbors for all three shapes
2015-07-14 added simulation logic, running with current neighborhood understanding (needs some updates for edge cases). Pauses simulation when changing shapes
2015-07-15 Created Pins file to alias all pin names to their functionality and convert them to masks.
2015-07-15 ISRs set up and AD interrupt handling brought over from test file.
2015-07-21 Altered Clock down to 1MHz for power saving and altered initializations accordingly. Began bringing initializations into main.
2015-07-21 Added code for driving APA102C LED and adjusted some relevant supporting code.
2015-07-22 Currently mic testing.
2015-08-14 State transmission and detection added. Simple rule set implemented. Small bug fixes.
    [AutomaTilesMain.c, Inits.c]
2015-08-17 Moved IR onto button pin. Tested new System.
2015-08-19 update simulation to save svg with a save button. Also change the grid dimensions
2015-09-21 Corrections to help with initialization and click detection accuracy. Build file updated to use debugger.
    [AutomaTilesMain.c]
2015-09-25 Added in synchronization pulses to ensure all boards step together.
2015-09-28 Temporarily disabled microphone. Added button debouncing.
2015-10-06 Added cases to ensure that interrupts only behave like mode 0 in mode 0.
2015-10-09 adding web interface for wireless pacemaker
2015-10-09 Added ESP8266 arduino code for communication testing.
2015-10-12 adding readme for arduino sketch
2015-10-16 Added power pin. Tweaked configurations slightly for new boards.
2015-10-16 More tweaks for new board
2015-10-23 fixed some syntax in previous ruleset code
    [AutomaTilesMain.c]
2015-10-25 Added and fully tested data parsing, along with a variety of bugfixes for reliable operation. Also added some helper functions for when changing modes.
    In addition, added arduino sketches used for testing pacmaking and data transmission
    [AutomaTilesMain.c, IRsendData.ino, Inits.c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]
2015-11-17 Sleep mode functionality added. Not fully stable. Issues with powerDownTimer.
    [AutomaTilesMain.c, Inits.c]
2015-11-18 disable interrupts when setting a variable equal to timer in microphone handling
2016-02-26 Created custom board type for Arduino IDE and modified Arduino core to be compatable with tile. Unstable build. Many things untested. Still modifying structure.
    [APA102C.c, AutomaTiles.c, Inits.c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]
2016-03-18 Fixed timer bug. Callbacks currently non-functional in Arduino. Currently debugging.
    [AutomaTiles.c]
2016-04-02 Fixed ADC problem but disallowing nesred interrupts and removed some long processes from within interrupts to account for change. Some code cleanup is still needed..
    [APA102C.c, AutomaTiles.c, Inits.c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]
2016-04-02 Update forestFires.c
    Updated code sketch to run with the latest Arduino build
2016-04-04 adding wire world to the examples for automatile rulesets
2016-04-08 Added long press detection with associated user settable callback. Fixed slight error in timer interrupt.
    [AutomaTiles.c]
2016-04-13 update the sketches to be arduino friendly
2016-04-15 Added in data sharing to Arduino core. Not yet tested. Assume Unstable.
    [AutomaTiles.c, main.c]
2016-04-22 update the forrest fire and fracture to use long button press
2016-04-22 click is the same as step, moved button down to where press is handled
2016-04-22 move wireworld and add comment to fracture
2016-04-22 format comment in wireworld
2016-04-22 update comment to include AutomaTiles board configuration note
2016-04-22 update the api readme to include new functions, long button press and timed callbacks
2016-04-25 updated the color gossip sketch to switch states when button pressed and in one state, transition from curent color to cyan in 1 second, and in the other state continue to cycle through all of the co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
2016-04-25 created a color gossip sketch that eases into colors. Still a little buggy from alone state, but close
    [ColorGossip.ino]
2016-04-26 added simple prototyping sketch with 7 colors, solid, slow and fast blink states achieved with simply button presses. No neighbor communication is happening at all
2016-04-26 updated the color gossip sketch to animate from cyan when cycling... still buggy though
    [ColorGossip.ino]
2016-04-26 fixed comment to describe the actual behavior of prototype colors
    [PrototypeColors.ino]
2016-05-02 7 color fade to latest color or blink orange if alone. Color doesn't yet take the quickest path
    [ColorGossip.ino]
2016-05-02 using the shortest path to animate from one color to the next
    [ColorGossip.ino]
2016-05-13 rotating color example working and color gossip is still problematic
    [ColorGossip.ino, ColorSpin.ino]
2016-05-13 Moved creation of buffers for gossiping into user space to free up large portion of RAM. Issues with color gossip were due to stack overflow corrupting globals. Programs that approach 375+ bytes of g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
    [AutomaTiles.c, ColorGossip.ino, main.c]
2016-05-27 updated color gossip to pulse white when alone, transition via the shortest path, and count if alone properly
    [ColorGossip.ino]
2016-05-27 flash to show heard snap... make fire go out after a single time step
    [ForestFires.ino]
2016-05-27 hardware test to show functionality of all sensors and inputs... starting with microphone
2016-05-27 readme for enclosure, soon to add files
2016-05-29 add 2450 battery
2016-05-29 add board design for lipo charger
    [AutomaTiles_LiPo_Charger.brd, AutomaTiles_LiPo_Charger.sch]
2016-05-29 adding Rev 3 board and BOM
    [Automatiles.brd, BOM_rev3.xlsx]
2016-06-13 re-adding long press timer
2016-06-13 added new battery size and charger parts to eagle library
2016-07-24 adding a lil more detail to the game platform document, testing inserting an image
2016-10-20 fixing the states to make them progress towards solved
    [HotColdPuzzle.ino]
2017-01-21 update the boards file to show AutomaTiles Legacy
2017-01-21 changing name of hardware type to AutomaTiles Legacy, to make it clear in Arduino, which version is which

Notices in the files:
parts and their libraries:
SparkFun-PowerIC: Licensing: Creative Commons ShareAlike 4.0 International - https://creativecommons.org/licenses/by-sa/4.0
